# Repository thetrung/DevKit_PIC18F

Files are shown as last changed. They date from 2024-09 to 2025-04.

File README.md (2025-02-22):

DevKit PIC18F/USB-B
=====================
Basic USB Type-B DevKit I made to learn about PIC18F45XX microcontroller.

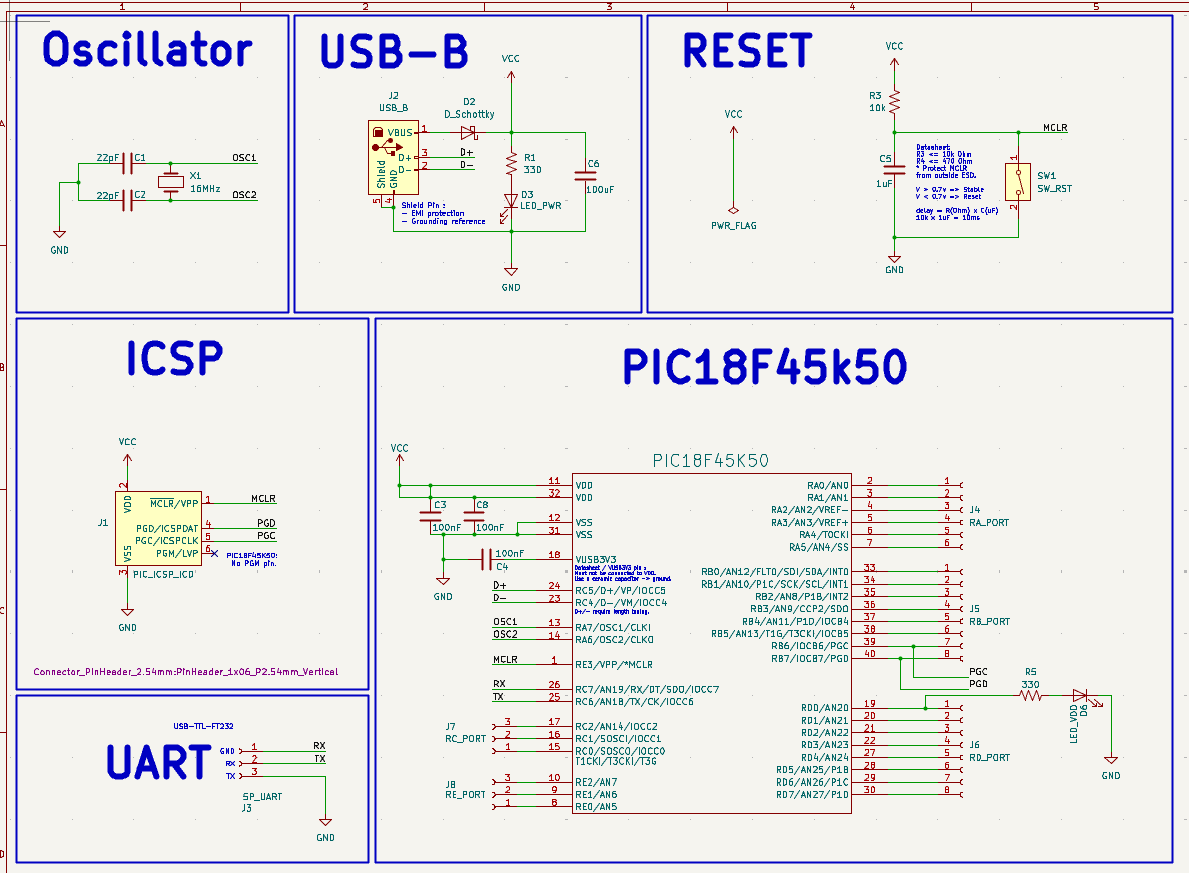
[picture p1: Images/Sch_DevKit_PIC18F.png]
overview


**It was initially for USB Type-C, but seem like I was wrong about how popular it actually is in my local stores, so change of plan : switching back to USB Type-B from Rev.2 for ease of self-soldering the boards. But very funny, on Rev.2, while changing the USB-Port, I realize how everything seem to be a little bit closer to what I think it should be. There were a short-circuit (for the 2nd-time) that I didn't realize right inside the USB-port.**

### 1. Basic functionality :
- USB-powered 5V supply.
- USB-HID controllable with PIC18F45k50 with D+/D- pins.
- Reset Button -> Trigger MLCR-pin pull-down -> GND.
- Programming/Debugging with PICKIT-3 via ICSP pins.
- 5 pluggable PORTS : RA, RB, RC, RD, RE.
- LED at RD0 for Blink Test.

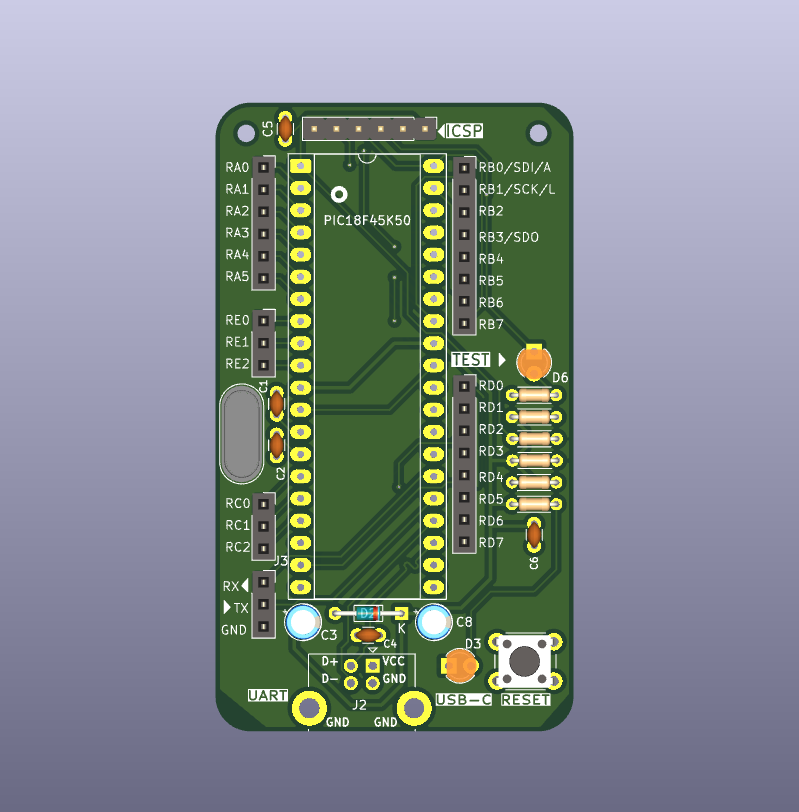
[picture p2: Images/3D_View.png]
3d_parts

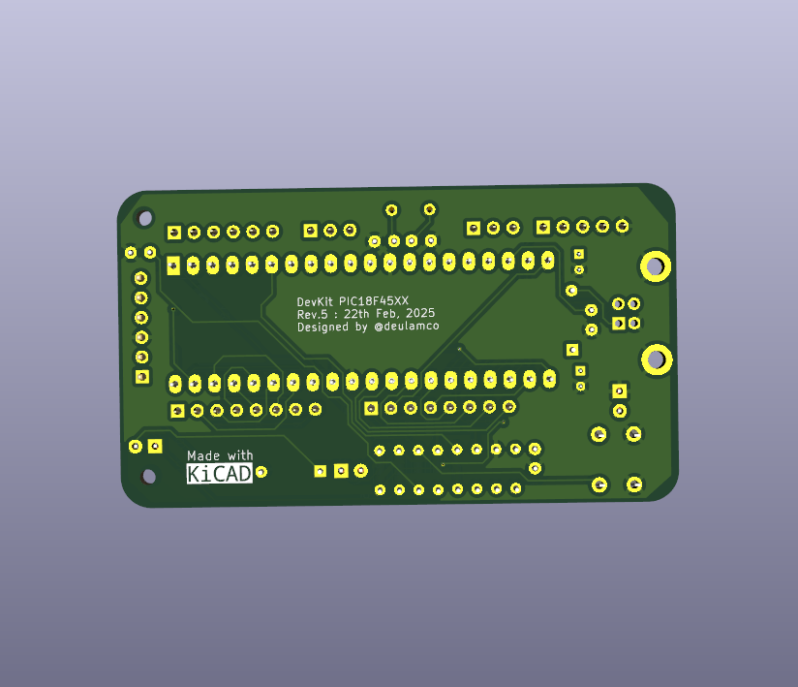
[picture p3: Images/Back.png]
back


### 2. TODO / Future extensions :
- Add Array : 
    - 4x4 12mm-Buttons pad.
    - 4x4 LEDs grid.
    - 16 Relays
      
- Add Gyro sensor.
- Add distance sensor.
- Add 12V Booster support.
- Add built-in UART w/ CH340.
- Add LCD2004 support, with/without I2C module.
- Add WIFI/LoRA/Bluetooth by ESP32 support (?).

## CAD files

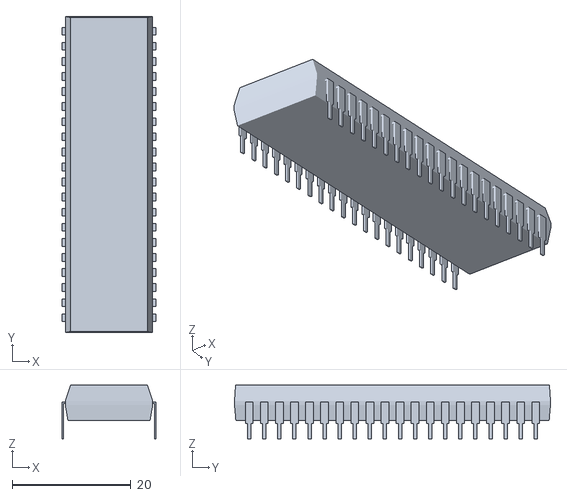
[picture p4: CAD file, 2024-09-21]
PIC18F45K50_I_P/PDIP40_P_MCH.stl
15.7 x 53.2 x 9.02

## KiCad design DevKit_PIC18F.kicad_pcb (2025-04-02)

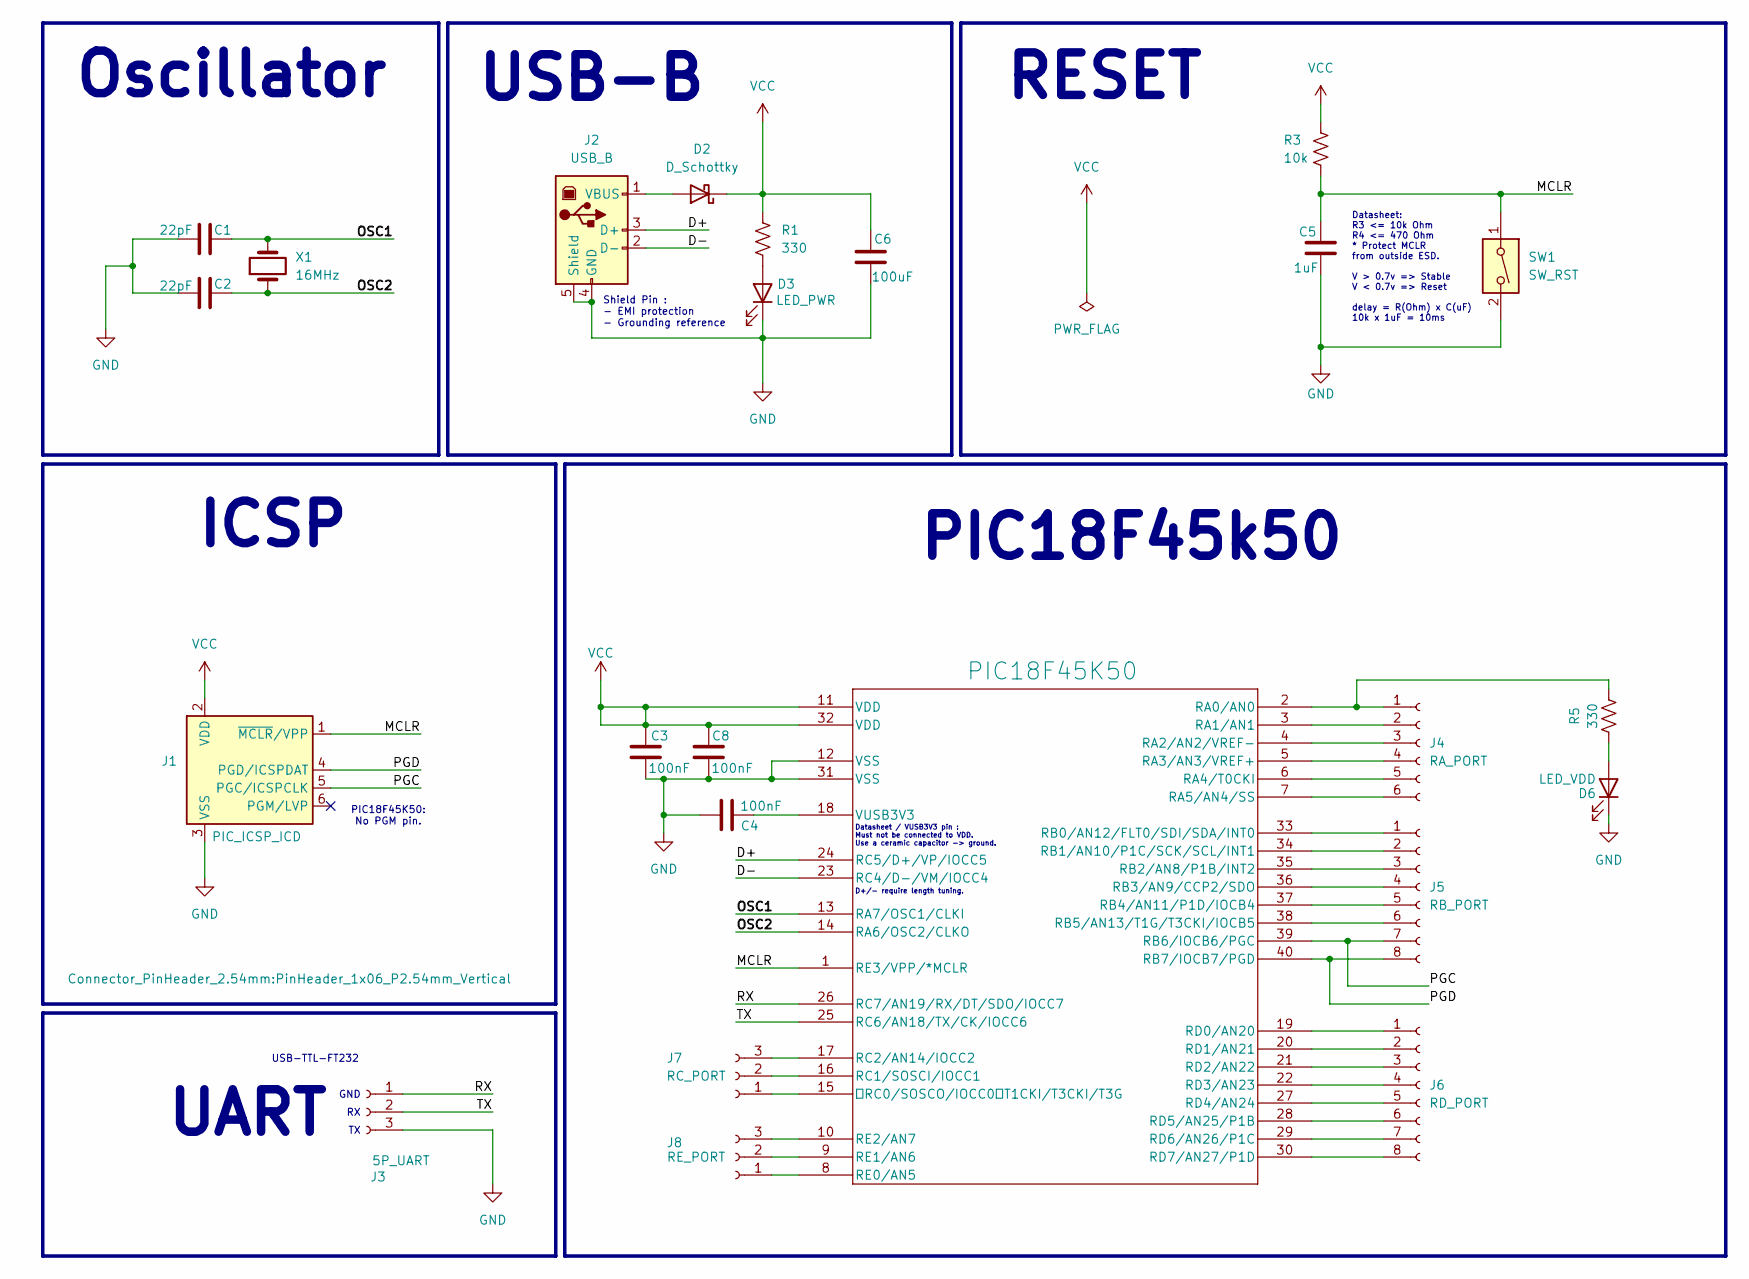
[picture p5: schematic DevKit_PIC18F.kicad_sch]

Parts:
C1, C2: 22pF; C_Disc_D3.0mm_W1.6mm_P2.50mm
C3, C8: 100nF; CP_Radial_D4.0mm_P2.00mm
C4: 100nF; C_Disc_D3.0mm_W1.6mm_P2.50mm
C5: 1uF; C_Disc_D3.0mm_W1.6mm_P2.50mm
C6: 100uF; C_Disc_D3.0mm_W1.6mm_P2.50mm
D2: D_Schottky; D_DO-34_SOD68_P7.62mm_Horizontal
D3: LED_PWR; LED_D3.0mm_FlatTop
D6: LED_VDD; LED_D3.0mm_FlatTop
J1: PIC_ICSP_ICD; PinHeader_1x06_P2.54mm_Vertical
J2: USB_B; USB_B_Lumberg_2411_02_Horizontal
J3: 5P_UART; PinSocket_1x03_P2.54mm_Vertical
J4: RA_PORT; PinSocket_1x06_P2.54mm_Vertical
J5: RB_PORT; PinSocket_1x08_P2.54mm_Vertical
J6: RD_PORT; PinSocket_1x08_P2.54mm_Vertical
J7: RC_PORT; PinSocket_1x03_P2.54mm_Vertical
J8: RE_PORT; PinSocket_1x03_P2.54mm_Vertical
PIC18F45K50: PIC18F45K50-I/P; DIP-40_W15.24mm_Socket_LongPads
R1, R5: 330; R_Axial_DIN0204_L3.6mm_D1.6mm_P5.08mm_Horizontal
R3: 10k; R_Axial_DIN0204_L3.6mm_D1.6mm_P5.08mm_Horizontal
SW1: SW_RST; SW_PUSH_6mm
X1: 16MHz; Crystal_HC49-4H_Vertical

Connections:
/D+: J2.3 (D+), PIC18F45K50.24 (RC5/D+/VP/IOCC5)
/D-: J2.2 (D-), PIC18F45K50.23 (RC4/D-/VM/IOCC4)
/MCLR: C5.2, J1.1 (~MCLR/VPP), PIC18F45K50.1 (RE3/VPP/*MCLR), R3.2, SW1.1; also elsewhere on the board
/OSC1: C1.1, PIC18F45K50.13 (RA7/OSC1/CLKI), X1.2
/OSC2: C2.1, PIC18F45K50.14 (RA6/OSC2/CLKO), X1.1
/PGC: J1.5 (PGC/ICSPCLK), J5.7, PIC18F45K50.39 (RB6/IOCB6/PGC)
/PGD: J1.4 (PGD/ICSPDAT), J5.8, PIC18F45K50.40 (RB7/IOCB7/PGD)
/RX: J3.1, PIC18F45K50.26 (RC7/AN19/RX/DT/SDO/IOCC7)
/TX: J3.2, PIC18F45K50.25 (RC6/AN18/TX/CK/IOCC6)
GND: C1.2, C2.2, C3.2, C4.1, C5.1, C6.1, C8.2, D3.1 (K), D6.1 (K), J1.3 (VSS), J2.4 (GND), J2.5 (Shield), J3.3, PIC18F45K50.12 (VSS), PIC18F45K50.31 (VSS), SW1.2
unnamed: D2.2 (A), J2.1 (VBUS)
unnamed: D3.2 (A), R1.2
unnamed: D6.2 (A), R5.1
unnamed: J4.1, PIC18F45K50.2 (RA0/AN0), R5.2
unnamed: J4.2, PIC18F45K50.3 (RA1/AN1)
unnamed: J4.3, PIC18F45K50.4 (RA2/AN2/VREF-)
unnamed: J4.4, PIC18F45K50.5 (RA3/AN3/VREF+)
unnamed 19: J4.5, PIC18F45K50.6 (RA4/T0CKI); also elsewhere on the board
unnamed: J4.6, PIC18F45K50.7 (RA5/AN4/SS)
unnamed: J5.1, PIC18F45K50.33 (RB0/AN12/FLT0/SDI/SDA/INT0)
unnamed: J5.2, PIC18F45K50.34 (RB1/AN10/P1C/SCK/SCL/INT1)
unnamed: J5.3, PIC18F45K50.35 (RB2/AN8/P1B/INT2)
unnamed: J5.4, PIC18F45K50.36 (RB3/AN9/CCP2/SDO)
unnamed: J5.5, PIC18F45K50.37 (RB4/AN11/P1D/IOCB4)
unnamed: J5.6, PIC18F45K50.38 (RB5/AN13/T1G/T3CKI/IOCB5)
unnamed: J6.1, PIC18F45K50.19 (RD0/AN20)
unnamed: J6.2, PIC18F45K50.20 (RD1/AN21)
unnamed: J6.3, PIC18F45K50.21 (RD2/AN22)
unnamed: J6.4, PIC18F45K50.22 (RD3/AN23)
unnamed: J6.5, PIC18F45K50.27 (RD4/AN24)
unnamed: J6.6, PIC18F45K50.28 (RD5/AN25/P1B)
unnamed: J6.7, PIC18F45K50.29 (RD6/AN26/P1C)
unnamed: J6.8, PIC18F45K50.30 (RD7/AN27/P1D)
unnamed: J7.1, PIC18F45K50.15 (RC0/SOSCO/IOCC0 T1CKI/T3CKI/T3G)
unnamed: J7.2, PIC18F45K50.16 (RC1/SOSCI/IOCC1)
unnamed: J7.3, PIC18F45K50.17 (RC2/AN14/IOCC2)
unnamed: J8.1, PIC18F45K50.8 (RE0/AN5)
unnamed: J8.2, PIC18F45K50.9 (RE1/AN6)
unnamed: J8.3, PIC18F45K50.10 (RE2/AN7)
unnamed: C4.2, PIC18F45K50.18 (VUSB3V3)
VCC: C3.1, C6.2, C8.1, D2.1 (K), J1.2 (VDD), PIC18F45K50.11 (VDD), PIC18F45K50.32 (VDD), R1.1, R3.1; also elsewhere on the board

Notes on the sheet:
RESET
USB-B
D+/- require length tuning.
ICSP
Shield Pin : - EMI protection - Grounding reference
Datasheet / VUSB3V3 pin : Must not be connected to VDD. Use a ceramic capacitor -> ground.
GND
UART
Datasheet: R3 <= 10k Ohm R4 <= 470 Ohm * Protect MCLR from outside ESD. V > 0.7v => Stable V < 0.7v => Reset delay = R(Ohm) x C(uF) 10k x 1uF = 10ms
USB-TTL-FT232
Oscillator
PIC18F45K50: No PGM pin.
PIC18F45k50

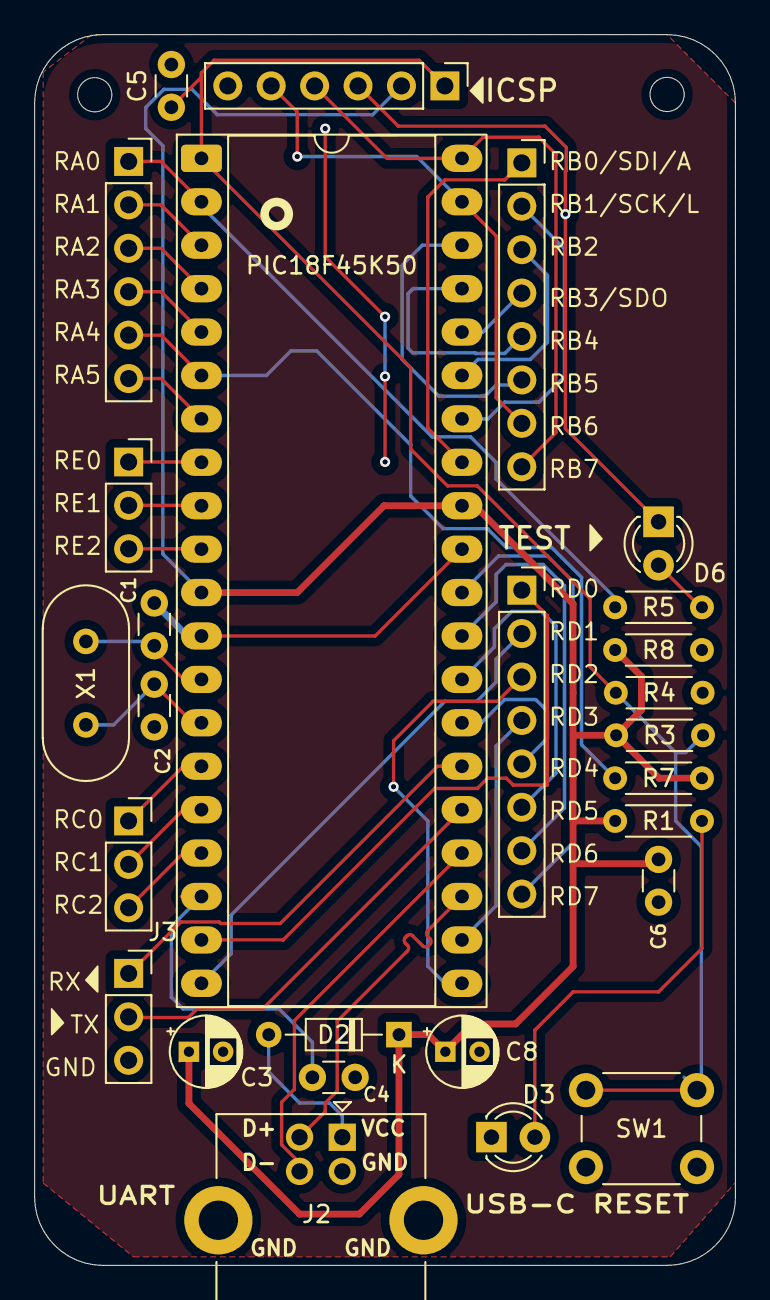
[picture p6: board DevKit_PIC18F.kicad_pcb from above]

Board: 2 copper layers, 41.0 x 72.0 mm, 27 parts (0 on the bottom side), 41 nets.

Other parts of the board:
R4: 470; R_Axial_DIN0204_L3.6mm_D1.6mm_P5.08mm_Horizontal
R7: 10k; R_Axial_DIN0204_L3.6mm_D1.6mm_P5.08mm_Horizontal
R8: 330; R_Axial_DIN0204_L3.6mm_D1.6mm_P5.08mm_Horizontal

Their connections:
/MCLR: R4.1; also elsewhere on the board
unnamed 19: R7.2; also elsewhere on the board
VCC: R7.1, R8.1; also elsewhere on the board

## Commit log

2024-09-21 Finished basic schematic for PIC18F45k50 Dev Board.
    [DevKit_PIC18F.kicad_pcb, DevKit_PIC18F.kicad_sch, PDIP40_P_MCH.stl]
2024-09-22 Change USB-B -> USB-C & Added EdgeCut.
    [DevKit_PIC18F.kicad_pcb, DevKit_PIC18F.kicad_sch]
2024-09-22 Routed & Finished Rev.1
    [DevKit_PIC18F.kicad_pcb, DevKit_PIC18F.kicad_sch]
2024-09-22 Fixed Crystal Error & re-routed some more.
    [DevKit_PIC18F.kicad_pcb, DevKit_PIC18F.kicad_sch]
2024-09-22 refine routing
    [DevKit_PIC18F.kicad_pcb, DevKit_PIC18F.kicad_sch]
2024-09-23 Added ICSP LED, D+/- tuned length, Cap placement/footprint update.
    [DevKit_PIC18F.kicad_pcb, DevKit_PIC18F.kicad_sch]
2024-09-23 Add LED/Diode-S->ICSP.
    [DevKit_PIC18F.kicad_pcb, DevKit_PIC18F.kicad_sch]
2024-09-23 refined & ordered to fabricate test pcs.
    [DevKit_PIC18F.kicad_pcb, DevKit_PIC18F.kicad_sch]
2024-09-25 Switch USB-C -> USB-B for availability.
    [DevKit_PIC18F.kicad_pcb, DevKit_PIC18F.kicad_sch]
2024-09-25 Refine/Fix Short-circuit on USB-B
    [DevKit_PIC18F.kicad_pcb, DevKit_PIC18F.kicad_sch]
2024-09-25 refine schematic.
    [DevKit_PIC18F.kicad_sch]
2025-01-13 Fix Bug : remove bridge as we don't need it.
    [DevKit_PIC18F.kicad_pcb, DevKit_PIC18F.kicad_sch]
2025-02-22 update rev -> rev.3 13th Jan, 2025: remove bridge
    [DevKit_PIC18F.kicad_pcb]
2025-02-22 Updaet Rev.4 : Flip:ICSP+ Move->LED, +Test_LED->RD0, Group all Resistors.
    [DevKit_PIC18F.kicad_pcb, DevKit_PIC18F.kicad_sch]
2025-02-22 Rev.5 : remove redundant LED D1
    [DevKit_PIC18F.kicad_pcb, DevKit_PIC18F.kicad_sch]
2025-02-22 merged changes
    [DevKit_PIC18F.kicad_pcb]
2025-02-27 rev.6: fixed LED-D6 -> GND instead VCC pull-up style.
    [DevKit_PIC18F.kicad_pcb, DevKit_PIC18F.kicad_sch]
2025-02-28 migrate -> KiCAD 9.0.0
    [DevKit_PIC18F.kicad_pcb, DevKit_PIC18F.kicad_sch, PDIP40_P_MCH.stl]
2025-03-08 Fix PWR_Flag & GND on PCB
    [DevKit_PIC18F.kicad_pcb, DevKit_PIC18F.kicad_sch]
2025-04-02 Update Rev.8: Fix SCH bug, remove D/R/L from ISCP & D6->RA0
    [DevKit_PIC18F.kicad_pcb, DevKit_PIC18F.kicad_sch]
